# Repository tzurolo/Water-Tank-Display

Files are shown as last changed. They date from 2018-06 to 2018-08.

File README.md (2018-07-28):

# Water-Tank-Display

Display module for the Water Tank Monitor.

It will be located in the pump house.

From there it will also monitor mains status and the operation of the pump.

It is based on the Adafruit Feather FONA 32u4 cellular module and an Adafruit TFT display.

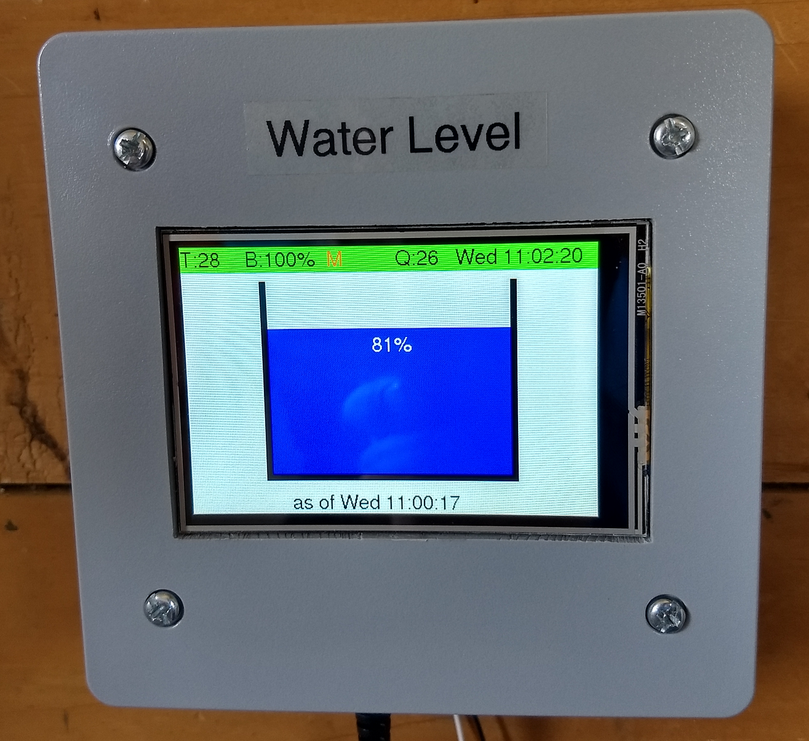
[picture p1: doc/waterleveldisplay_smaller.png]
Water Level Display


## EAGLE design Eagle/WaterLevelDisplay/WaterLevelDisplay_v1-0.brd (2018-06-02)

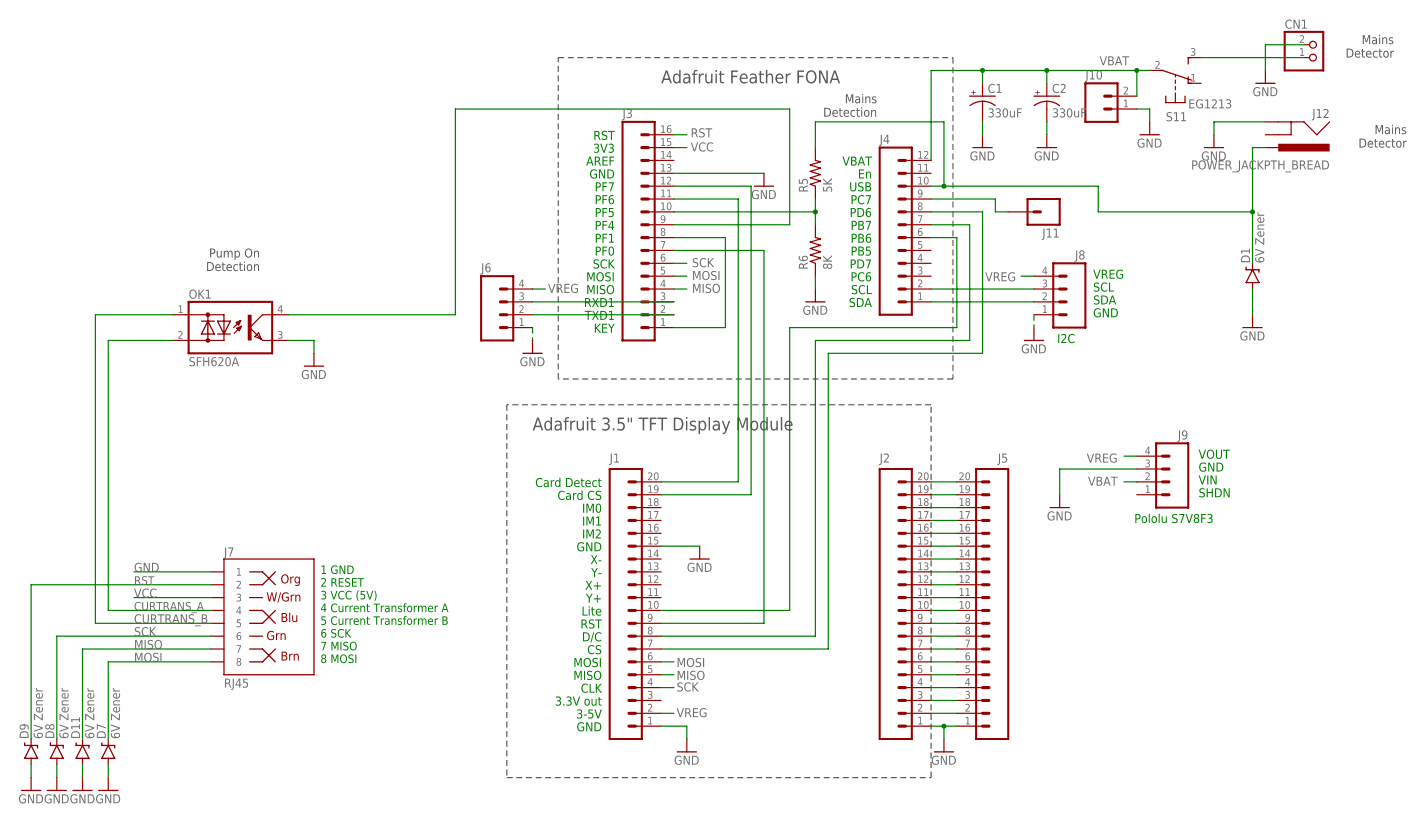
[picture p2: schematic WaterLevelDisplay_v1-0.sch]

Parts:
C1, C2: 330uF; CPOL-RADIAL-100UF-25V
CN1: JST_2PIN-SMT-RA; JST-PH-2-SMT-RA
D1, D7, D8, D9, D11: 6V Zener; DIODE-ZENER
J1, J2, J5: M20NOSILK; 1X20_NOSILK
J3: M161X16_NO_SILK; 1X16_NO_SILK
J4: M12NO_SILK; 1X12_NO_SILK
J6, J8, J9: M04PTH; 1X04
J7: RJ45; RJ45-8
J10: M02PTH; 1X02
J11: M01PTH; 1X01
J12: POWER_JACKPTH_BREAD; POWER_JACK_PTH_BREAD
OK1: SFH620A; DIL04
R5: 5K; 0204/5
R6: 8K; 0204/5
S1: EG1213

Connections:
CURTRANS_A: J7.4, OK1.2 (AC2)
CURTRANS_B: J7.5, OK1.1 (AC1)
GND: C1.2 (-), C2.2 (-), CN1.2 (1), D1.P$2 (A), D7.P$2 (A), D8.P$2 (A), D9.P$2 (A), D11.P$2 (A), J1.1, J1.15, J2.1, J3.13, J5.1, J6.1, J7.1, J8.1, J9.3, J10.1, J12.GND, OK1.3 (E), R6.1
MISO: D11.P$1 (C), J1.5, J3.4, J7.7
MOSI: D7.P$1 (C), J1.6, J3.5, J7.8
unnamed: CN1.1 (2), S1.3 (S)
unnamed: J2.2, J5.2
unnamed: J2.3, J5.3
unnamed: J2.4, J5.4
unnamed: J2.5, J5.5
unnamed: J3.3, J6.3
unnamed: J2.6, J5.6
unnamed: J2.7, J5.7
unnamed: J4.9, J11.1
unnamed: J2.8, J5.8
unnamed: J2.9, J5.9
unnamed: J2.10, J5.10
unnamed: J2.11, J5.11
unnamed: J2.12, J5.12
unnamed: J3.1, J3.8
unnamed: J2.13, J5.13
unnamed: D1.P$1 (C), J4.10, J12.PWR, R5.2
unnamed: J3.10, R5.1, R6.2
unnamed: J2.14, J5.14
unnamed: J2.15, J5.15
unnamed: J2.16, J5.16
unnamed: J2.17, J5.17
unnamed: J2.18, J5.18
unnamed: J2.19, J5.19
unnamed: J2.20, J5.20
unnamed: J3.2, J6.2
unnamed: J1.8, J4.7
unnamed: J1.19, J3.12
unnamed: J1.20, J3.11
unnamed: J1.10, J4.6
unnamed: J3.9, OK1.4 (C)
unnamed: J1.7, J4.8
unnamed: J1.9, J3.7
unnamed: J4.1, J8.2
unnamed: J4.2, J8.3
RST: D9.P$1 (C), J3.16, J7.2
SCK: D8.P$1 (C), J1.4, J3.6, J7.6
VBAT: C1.1 (+), C2.1 (+), J4.12, J9.2, J10.2, S1.2
VCC: J3.15, J7.3
VREG: J1.2, J6.4, J8.4, J9.4

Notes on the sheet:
Mains Detection
1 GND 2 RESET 3 VCC (5V) 4 Current Transformer A 5 Current Transformer B 6 SCK 7 MISO 8 MOSI
GND
3.3V out
CLK
MISO
MOSI
D/C
RST
Lite
IM2
IM1
IM0
Card CS
Card Detect
3-5V
3V3
AREF
PF7
PF6
PF5
PF1
PF0
SCK
PF4
TXD1
KEY
RXD1
VBAT
USB
PC7
PD6
PB7
PB6
PB5
PD7
PC6
SCL
SDA
Adafruit Feather FONA

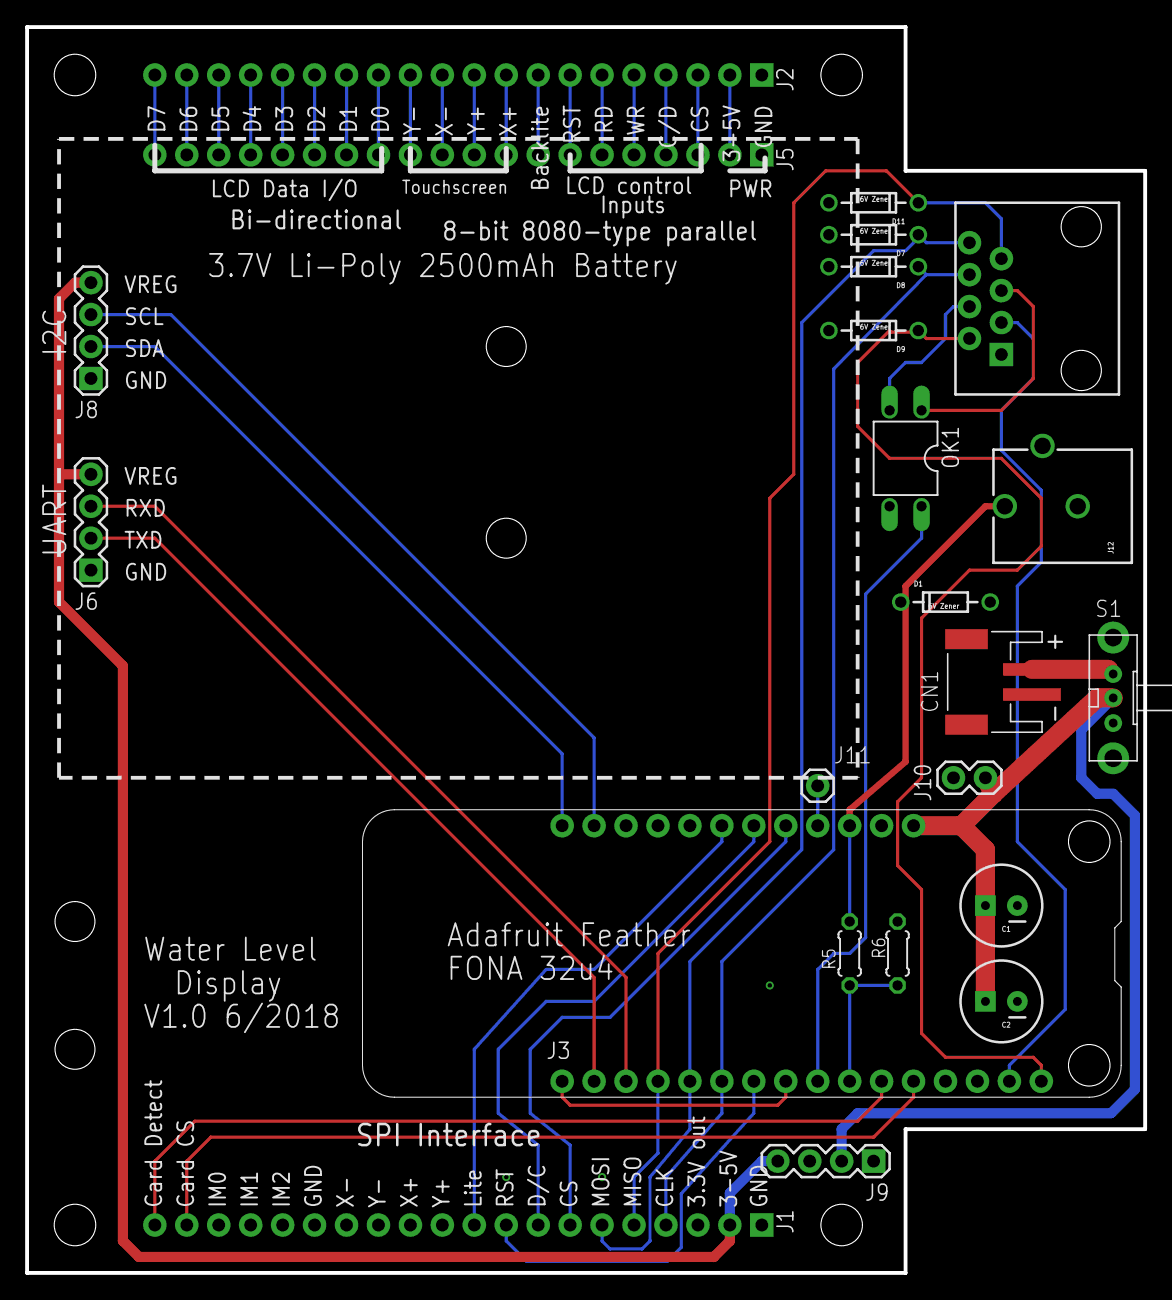
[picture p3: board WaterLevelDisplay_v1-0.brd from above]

Board: 2 copper layers, 88.9 x 99.1 mm, 30 parts (0 on the bottom side), 45 nets.

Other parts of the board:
U$1, U$2, U$3, U$4, U$5, U$6: STAND-OFF

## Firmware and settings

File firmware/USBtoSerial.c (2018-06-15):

/*
             LUFA Library
     Copyright (C) Dean Camera, 2015.

  dean [at] fourwalledcubicle [dot] com
           www.lufa-lib.org
*/

/*
  Copyright 2015  Dean Camera (dean [at] fourwalledcubicle [dot] com)

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
  The author disclaims all warranties with regard to this
  software, including all implied warranties of merchantability
  and fitness.  In no event shall the author be liable for any
  special, indirect or consequential damages or any damages
  whatsoever resulting from loss of use, data or profits, whether
  in an action of contract, negligence or other tortious action,
  arising out of or in connection with the use or performance of
  this software.
*/

/** \file
 *
 *  Main source file for the USBtoSerial project. This file contains the main tasks of
 *  the project and is responsible for the initial application hardware configuration.
 */

#include "USBtoSerial.h"
#include "USBTerminal.h"
#include "EEPROMStorage.h"
#include "SystemTime.h"
#include "IOPortBitfield.h"
#include "SIM800.h"
#include "Console.h"
#include "CellularComm_SIM800.h"
#include "CellularComm_SIM800.h"
#include "CellularTCPIP_SIM800.h"
#include "TCPIPConsole.h"
#include "TFT_HXD8357D.h"
#include "Display.h"
#include "PowerMonitor.h"
#include "SDCard.h"
#include "SoftwareSerialRx0.h"
#include "SoftwareSerialTx.h"
#include "ADCManager.h"
#include "InternalTemperatureMonitor.h"
#include "WaterLevelDisplay.h"
#include "RAMSentinel.h"

/** Configures the board hardware and chip peripherals for the demo's functionality. */
void Initialize (void)
{
    // enable watchdog timer
    wdt_enable(WDTO_500MS);

    /* Disable clock division */
//	clock_prescale_set(clock_div_1);

    EEPROMStorage_Initialize();
    SystemTime_Initialize();
    SoftwareSerialRx0_Initialize();
    SoftwareSerialTx_Initialize();
    Console_Initialize();
    CellularComm_Initialize();
    CellularTCPIP_Initialize();
    TCPIPConsole_Initialize();
    Display_Initialize();
    TFT_HXD8357D_Initialize();
    PowerMonitor_Initialize();
    SDCard_Initialize();
    ADCManager_Initialize();
    InternalTemperatureMonitor_Initialize();
    RAMSentinel_Initialize();
    USBTerminal_Initialize();
    WaterLevelDisplay_Initialize();
}

/** Main program entry point. This routine contains the overall program flow, including initial
 *  setup of all components and the main program loop.
 */
int main(void)
{
    Initialize();
    sei();
    for (;;) {
        if (!RAMSentinel_sentinelIntact()) {
            Console_printP(PSTR("stack collision!"));
            SystemTime_commenceShutdown();
        }

        // run all the tasks
        SystemTime_task();
        ADCManager_task();
        InternalTemperatureMonitor_task();
        SIM800_task();
        Console_task();
        USBTerminal_task();
        TCPIPConsole_task();
        CellularComm_task();
        PowerMonitor_task();
        WaterLevelDisplay_task();
        Display_task();
        TFT_HXD8357D_task();

        // daily reboot logic, but not in the middle of display task activity
        if (WaterLevelDisplay_taskIsIdle() &&
             (!SystemTime_shuttingDown())) {
            const uint32_t uptime = SystemTime_uptime();
            const uint32_t rebootIntervalSeconds = (((uint32_t)EEPROMStorage_rebootInterval()) * 60);
            if (uptime > rebootIntervalSeconds) {
                SystemTime_commenceShutdown();
            }
        }
    }

    return 0;
}

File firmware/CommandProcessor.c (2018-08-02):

//
// Command processor
//
// Interprets and executes commands from SMS or the console
//

#include "CommandProcessor.h"

#include <stdlib.h>
#include <avr/pgmspace.h>
#include <avr/power.h>

#if BYTEQUEUE_HIGHWATERMARK_ENABLED
#include "SoftwareSerialRx0.h"
#include "SoftwareSerialTx.h"
#endif
#include "SystemTime.h"
#include "CellularComm_SIM800.h"
#include "CellularTCPIP_SIM800.h"
#include "Console.h"
#include "EEPROM_Util.h"
#include "EEPROMStorage.h"
#include "WaterLevelDisplay.h"
#include "StringUtils.h"
#include "UART_async.h"
#include "TFT_HXD8357D.h"
#include "PowerMonitor.h"
#include "SDCard.h"
#include "Display.h"

typedef void (*StringProvider)(
    CharString_t *string);

CharString_define(80, CommandProcessor_incomingCommand)
CharString_define(100, CommandProcessor_commandReply)

// command keywords
static char pinP[]              PROGMEM = "PIN";
static char cipqsendP[]         PROGMEM = "cipqsend";
static char apnP[]              PROGMEM = "APN";
static char offP[]              PROGMEM = "off";
static char onP[]               PROGMEM = "on";
static char idP[]               PROGMEM = "id";
static char ipserverP[]         PROGMEM = "ipserver";
static char tCalOffsetP[]       PROGMEM = "tCalOffset";
static char utcOffsetP[]        PROGMEM = "utcOffset";
static char batCalP[]           PROGMEM = "batCal";
static char wlmTimeoutP[]       PROGMEM = "wlmTimeout";
static char rebootP[]           PROGMEM = "reboot";
static char sampleIntervalP[]   PROGMEM = "sampleInterval";
static char logIntervalP[]      PROGMEM = "logInterval";
static char logDelayP[]         PROGMEM = "logDelay";
static char thingspeakP[]       PROGMEM = "thingspeak";

void CommandProcessor_createStatusMessage (
    CharString_t *msg)
{
    CharString_clear(msg);
    SystemTime_t curTime;
    SystemTime_getCurrentTime(&curTime);
    SystemTime_appendToString(&curTime, false, msg);
    CharString_appendP(PSTR(",st:"), msg);
    StringUtils_appendDecimal(CellularComm_state(), 2, 0, msg);
    if (CellularComm_stateIsTCPIPSubtask(CellularComm_state())) {
        CharString_appendC('.', msg);
        StringUtils_appendDecimal(CellularTCPIP_state(), 2, 0, msg);
    }
    CharString_appendC(',', msg);
    StringUtils_appendDecimal(WaterLevelDisplay_state(), 1, 0, msg);
    CharString_appendP(PSTR(",Vc:"), msg);
    StringUtils_appendDecimal(CellularComm_batteryMillivolts(), 1, 3, msg);
    CharString_appendP(PSTR(",r:"), msg);
    StringUtils_appendDecimal((int)CellularComm_registrationStatus(), 1, 0, msg);
    CharString_appendP(PSTR(",q:"), msg);
    StringUtils_appendDecimal(CellularComm_SignalQuality(), 2, 0, msg);
    CharString_appendP(PSTR(",m:"), msg);
    StringUtils_appendDecimal(PowerMonitor_mainsOn(), 1, 0, msg);
    CharString_appendP(PSTR(",p:"), msg);
    StringUtils_appendDecimal(PowerMonitor_pumpOn(), 1, 0, msg);
    CharString_appendP(PSTR(",T:"), msg);
    uint8_t minTicks;
    uint8_t maxTicks;
    SystemTime_getTaskTickRange(&minTicks, &maxTicks);
    StringUtils_appendDecimal(minTicks, 1, 0, msg);
    CharString_appendC('-', msg);
    StringUtils_appendDecimal(maxTicks, 1, 0, msg);
    SystemTime_resetTaskTickRange();
    CharString_appendP(PSTR("  "), msg);
}

static int16_t scanIntegerToken (
    CharStringSpan_t *str,
    bool *isValid)
{
    StringUtils_skipWhitespace(str);
    int16_t value = 0;
    StringUtils_scanInteger(str, isValid, &value, str);
    return value;
}

static uint32_t scanIntegerU32Token (
    CharStringSpan_t *str,
    bool *isValid)
{
    StringUtils_skipWhitespace(str);
    uint32_t value = 0;
    StringUtils_scanIntegerU32(str, isValid, &value, str);
    return value;
}

static void beginJSON (
    CharString_t *str)
{
    CharString_copyP(PSTR("{"), str);
}

static void continueJSON (
    CharString_t *str)
{
    CharString_appendC(',', str);
}

static void endJSON (
    CharString_t *str)
{
    CharString_appendC('}', str);
}

static void appendJSONStrValue (
    PGM_P name,
    StringProvider strProvider,
    CharString_t *str)
{
    CharString_appendC('\"', str);
    CharString_appendP(name, str);
    CharString_appendP(PSTR("\":\""), str);
    strProvider(str);
    CharString_appendC('\"', str);
}

static void appendJSONIntValue (
    PGM_P name,
    const int16_t value,
    CharString_t *str)
{
    CharString_appendC('\"', str);
    CharString_appendP(name, str);
    CharString_appendP(PSTR("\":"), str);
    StringUtils_appendDecimal(value, 1, 0, str);
}

static void appendJSONTimeValue (
    PGM_P name,
    const SystemTime_t *time,
    CharString_t *str)
{
    CharString_appendC('\"', str);
    CharString_appendP(name, str);
    CharString_appendP(PSTR("\":\""), str);
    SystemTime_appendToString(time, false, str);
    CharString_appendC('\"', str);
}

static void makeJSONStrValue (
    PGM_P name,
    StringProvider strProvider,
    CharString_t *str)
{
    beginJSON(str);
    appendJSONStrValue(name, strProvider, str);
    endJSON(str);
}

static void makeJSONIntValue (
    PGM_P name,
    const int16_t value,
    CharString_t *str)
{
    beginJSON(str);
    appendJSONIntValue(name, value, str);
    endJSON(str);
}
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

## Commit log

2018-05-29 initial board layout
    captured footprint of feather fona and TFT board
    [WaterLevelDisplay_v1-0.brd, WaterLevelDisplay_v1-0.sch]
2018-05-31 first round of layout
    [WaterLevelDisplay_v1-0.brd, WaterLevelDisplay_v1-0.sch]
2018-05-31 changes to suit PC board layout
2018-06-02 candidate for final
    [WaterLevelDisplay_v1-0.brd, WaterLevelDisplay_v1-0.sch]
2018-06-15 added ADC manager and temperature sensor
2018-06-16 display updates, fixed scanInteger neg bug
    [CommandProcessor.c, TFT_HXD8357D.c]

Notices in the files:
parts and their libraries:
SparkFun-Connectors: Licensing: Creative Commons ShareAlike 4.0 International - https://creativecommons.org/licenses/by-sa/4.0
